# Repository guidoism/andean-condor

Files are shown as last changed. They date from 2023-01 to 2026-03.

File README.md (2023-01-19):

# Andean Condor

48 key monoblock split keyboard

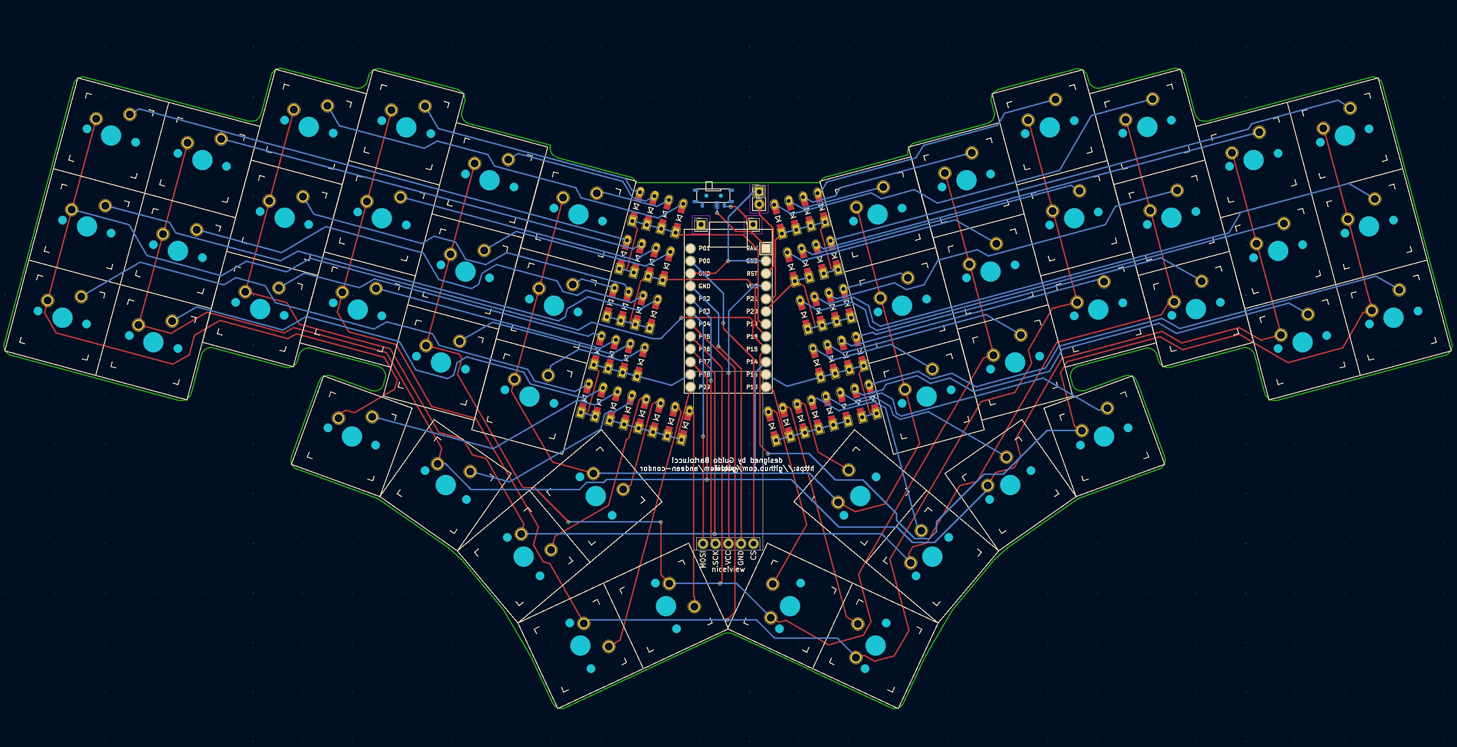
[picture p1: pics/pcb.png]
Picture of PCB


## Characteristics

- 3x6 core + 6 key thumb cluster per hand
- Pro-micro MCU footprint (note: it's right-side-up which apparently goes against the current trend)
- Nice!View headers (untested)

## Inspiration 

- Kyria -- A huge inpsiration, the thumb cluster in particular is taken directly from the Kyria
- Absolem -- Monoblock split and angles taken from Absolem

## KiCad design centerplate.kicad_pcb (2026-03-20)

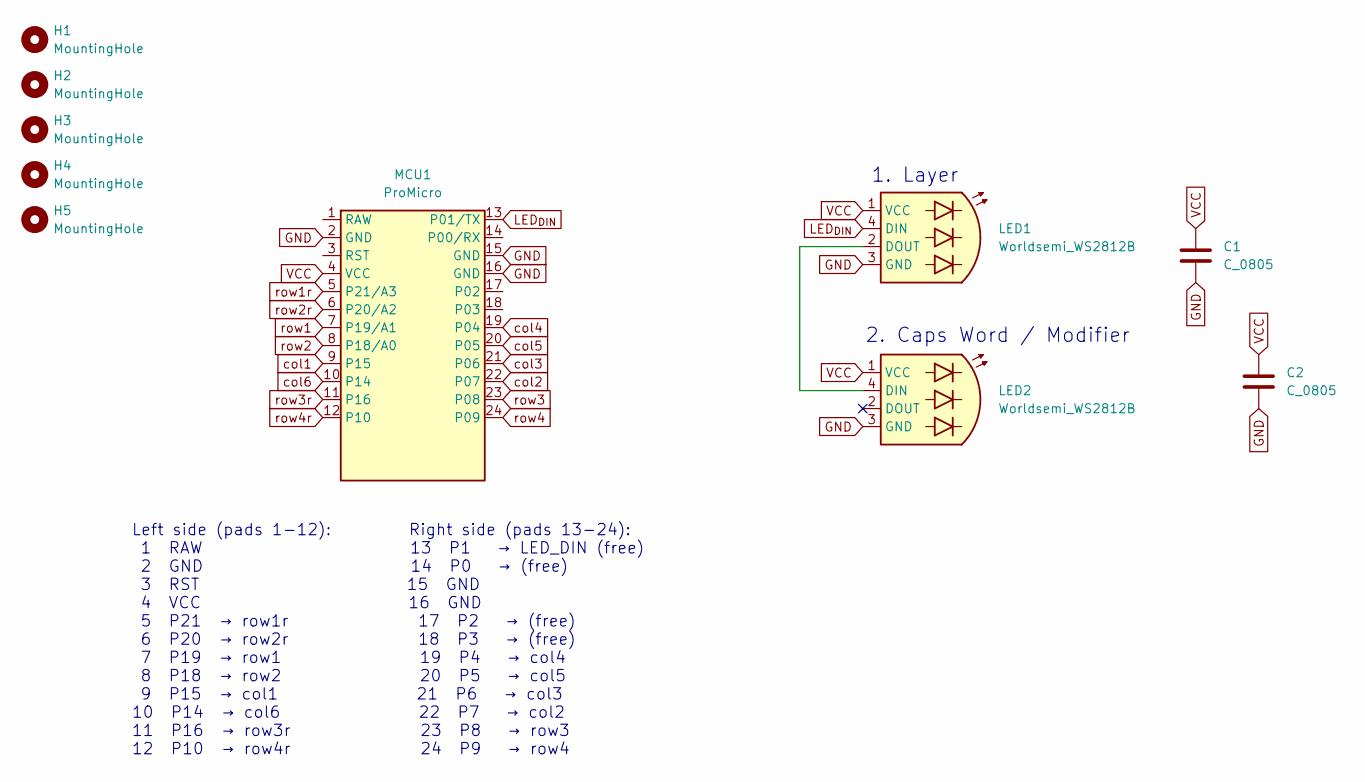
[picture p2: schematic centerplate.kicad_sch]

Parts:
C1, C2: C_0805; C_0805_2012Metric
H1, H2, H3, H4, H5: MountingHole; M2_HOLE_v3
LED1, LED2: Worldsemi_WS2812B; LED_WS2812B_PLCC4_5.0x5.0mm_P3.2mm
MCU1: ProMicro

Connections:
GND: C1.2, C2.2, LED1.3 (GND), LED2.3 (GND), MCU1.2 (GND), MCU1.15 (GND), MCU1.16 (GND)
LED_{DIN}: LED1.4 (DIN), MCU1.13 (P01/TX)
unnamed: LED1.2 (DOUT), LED2.4 (DIN)
VCC: C1.1, C2.1, LED1.1 (VCC), LED2.1 (VCC), MCU1.4 (VCC)
col1: MCU1.9 (P15)
col2: MCU1.22 (P07)
col3: MCU1.21 (P06)
col4: MCU1.19 (P04)
col5: MCU1.20 (P05)
col6: MCU1.10 (P14)
row1: MCU1.7 (P19/A1)
row1r: MCU1.5 (P21/A3)
row2: MCU1.8 (P18/A0)
row2r: MCU1.6 (P20/A2)
row3: MCU1.23 (P08)
row3r: MCU1.11 (P16)
row4: MCU1.24 (P09)
row4r: MCU1.12 (P10)

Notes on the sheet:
Left side (pads 1-12): Right side (pads 13-24): 1 RAW 13 P1 → LED_DIN (free) 2 GND 14 P0 → (free) 3 RST 15 GND 4 VCC 16 GND 5 P21 → row1r 17 P2 → (free) 6 P20 → row2r 18 P3 → (free) 7 P19 → row1 19 P4 → col4 8 P18 → row2 20 P5 → col5 9 P15 → col1 21 P6 → col3 10 P14 → col6 22 P7 → col2 11 P16 → row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
2. Caps Word / Modifier
1. Layer

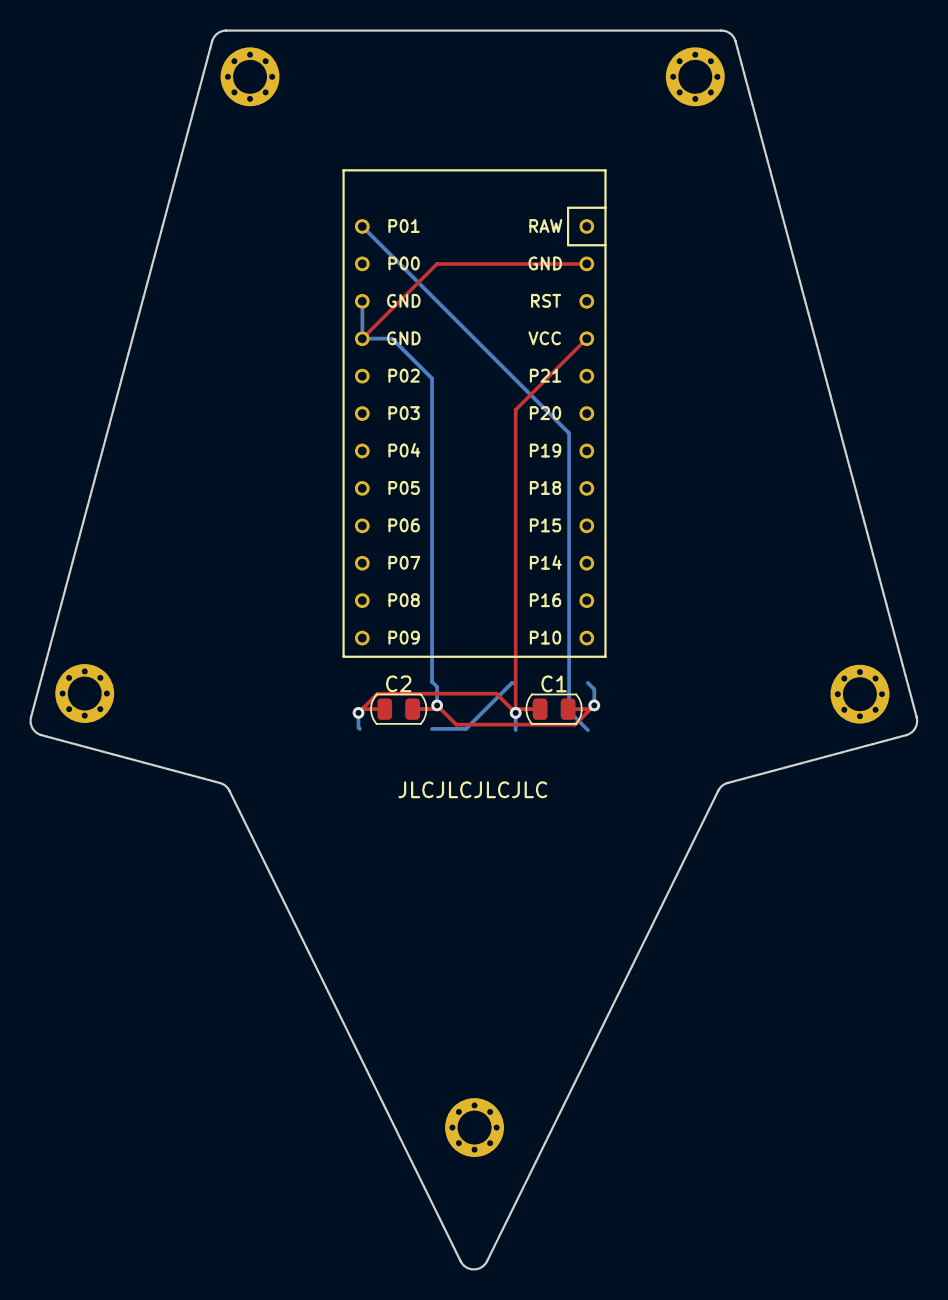
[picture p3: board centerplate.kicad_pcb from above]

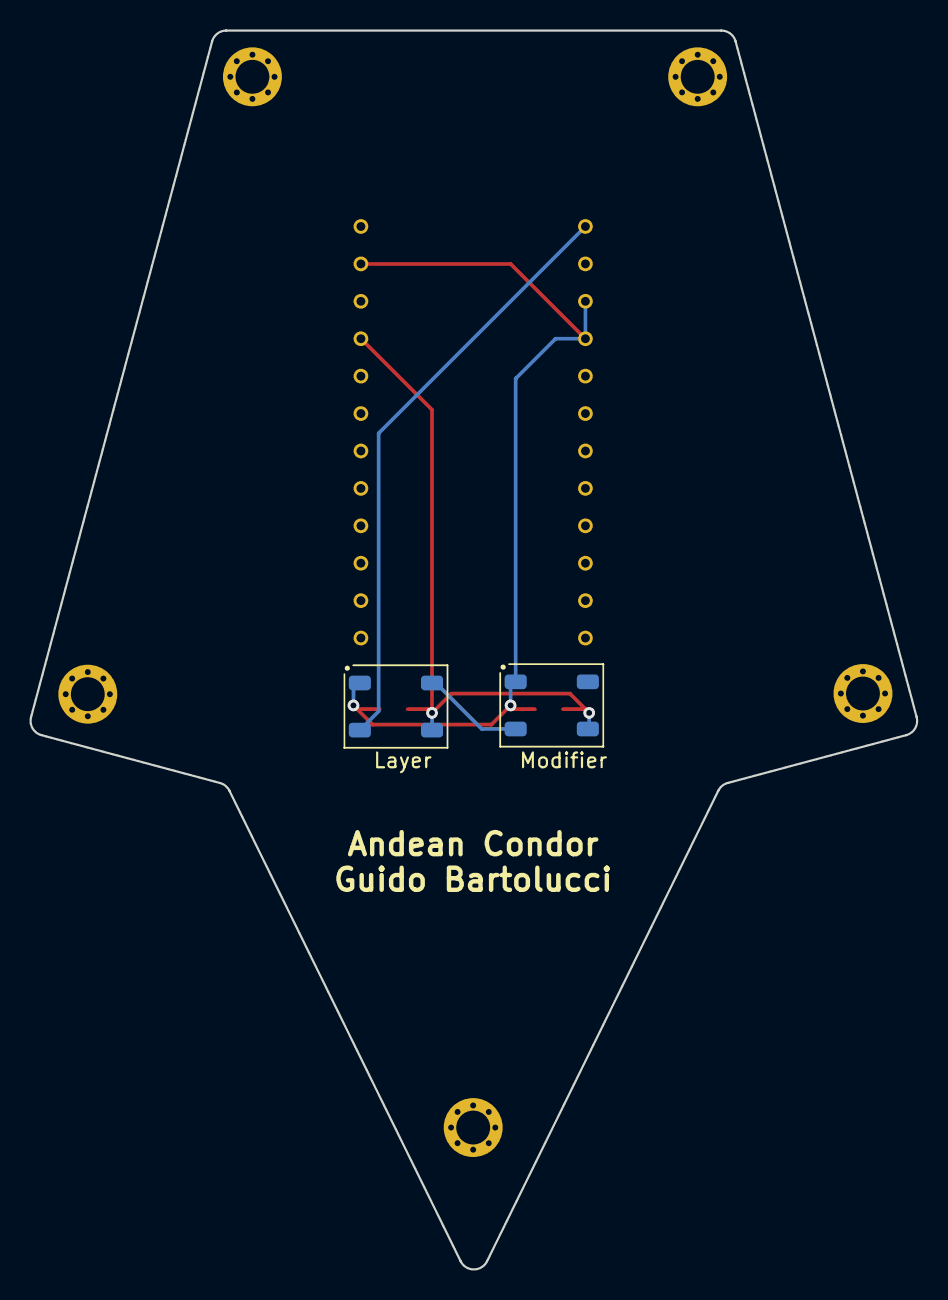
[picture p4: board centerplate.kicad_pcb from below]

Board: 2 copper layers, 60.2 x 84.1 mm, 10 parts (2 on the bottom side), 4 nets.

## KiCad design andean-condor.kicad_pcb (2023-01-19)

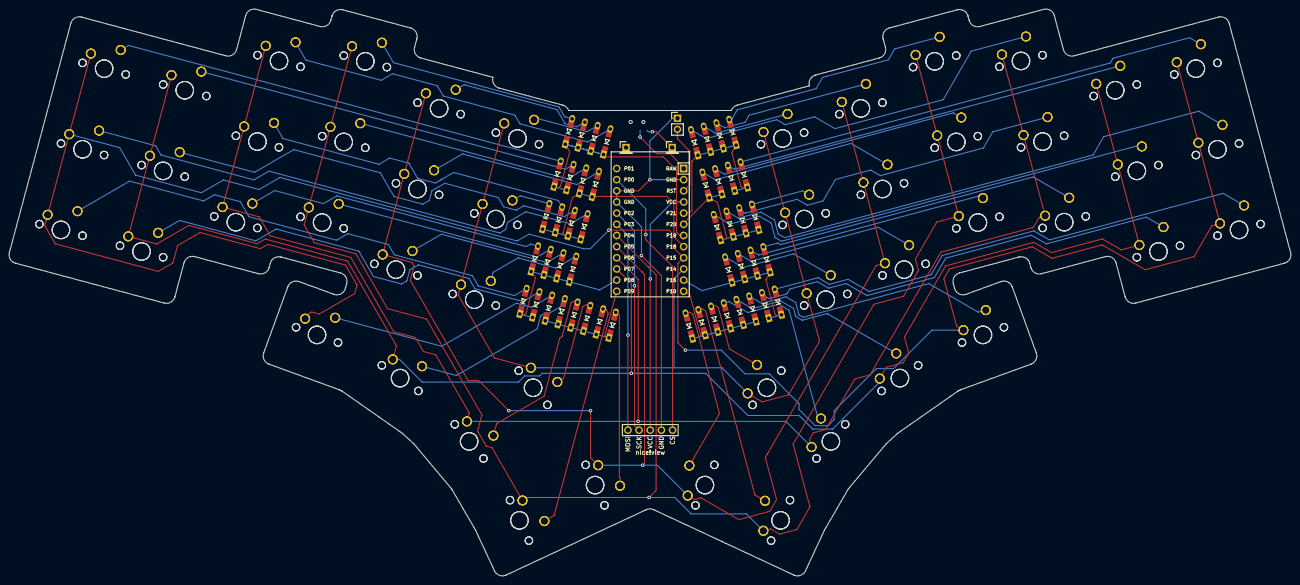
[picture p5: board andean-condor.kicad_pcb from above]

Board: 2 copper layers, 291.8 x 129.0 mm, 147 parts (1 on the bottom side), 68 nets.

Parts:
D33, D33#2, D34, D34#2, D35, D35#2, D36, D36#2, D37, D37#2, D38, D38#2, D39, D39#2, D40, D40#2, D41, D41#2, D42, D42#2, D43, D43#2, D44, D44#2, D45, D45#2, D46, D46#2, D47, D47#2, D48, D48#2, D49, D49#2, D50, D50#2, D51, D51#2, D52, D52#2, D53, D54, D55, D56, D57, D58, D59, D60: D; D3_TH_SMD_v2
MCU1: ProMicro
S1, S2, S3, S4, S5, S6, S7, S8, S9, S10, S11, S12, S13, S14, S15, S16, S17, S18, S19, S20, S21, S22, S23, S24, S25, S26, S27, S28, S29, S30, S31, S32, S33, S34, S35, S36, S37, S38, S39, S40, S41, S42, S43, S44, S45, S46, S47, S48, S49, S50, S51, S52, S53, S54, S55, S56, S57, S58, S59, S60, S61, S62, S63, S64, S65, S66, S67, S68, S69, S70, S71, S72, S73, S74, S75, S76, S77, S78, S79, S80, S81, S82, S83, S84, S85, S86, S87, S88, S89, S90, S91, S92, S93, S94, S95, S96: MX
SW1: SW_SPDT; switch-MSK-12C02-smd
display*: nice!view; nice_view

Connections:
GND: MCU1.2, MCU1.15, MCU1.16, display*.4
P0: MCU1.14, display*.5
P2: MCU1.17, display*.2
P3: MCU1.18, display*.1
RAW: MCU1.1, SW1.2
VCC: MCU1.4, display*.3
col1: MCU1.9, S1.2, S2.2, S3.2, S19.2, S25.2, S26.2, S27.2, S43.2, S49.2, S50.2, S51.2, S67.2, S73.2, S74.2, S75.2, S91.2
col2: MCU1.22, S4.2, S5.2, S6.2, S20.2, S28.2, S29.2, S30.2, S44.2, S52.2, S53.2, S54.2, S68.2, S76.2, S77.2, S78.2, S92.2
col3: MCU1.21, S7.2, S8.2, S9.2, S21.2, S31.2, S32.2, S33.2, S45.2, S55.2, S56.2, S57.2, S69.2, S79.2, S80.2, S81.2, S93.2
col4: MCU1.19, S10.2, S11.2, S12.2, S23.2, S34.2, S35.2, S36.2, S47.2, S58.2, S59.2, S60.2, S71.2, S82.2, S83.2, S84.2, S95.2
col5: MCU1.20, S13.2, S14.2, S15.2, S24.2, S37.2, S38.2, S39.2, S48.2, S61.2, S62.2, S63.2, S72.2, S85.2, S86.2, S87.2, S96.2
col6: MCU1.10, S16.2, S17.2, S18.2, S22.2, S40.2, S41.2, S42.2, S46.2, S64.2, S65.2, S66.2, S70.2, S88.2, S89.2, S90.2, S94.2
far_thumb: D55.2, S23.1, S95.1
far_top: D56.2, S24.1, S96.1
farpinky_bottom: D49.2, S1.1, S73.1
farpinky_home: D44#2.2, S2.1, S74.1
farpinky_top: D37#2.2, S3.1, S75.1
home_thumb: D53.2, S21.1, S93.1
home_top: D54.2, S22.1, S94.1
index_bottom: D47.2, S13.1, S85.1
index_home: D40#2.2, S14.1, S86.1
index_top: D34#2.2, S15.1, S87.1
inner_bottom: D48.2, S16.1, S88.1
inner_home: D41#2.2, S17.1, S89.1
inner_top: D35.2, S18.1, S90.1
middle_bottom: D46.2, S10.1, S82.1
middle_home: D39#2.2, S11.1, S83.1
middle_top: D33#2.2, S12.1, S84.1
mirror_far_thumb: D50.2, S47.1, S71.1
mirror_far_top: D49#2.2, S48.1, S72.1
mirror_farpinky_bottom: D60.2, S25.1, S49.1
mirror_farpinky_home: D42.2, S26.1, S50.1
mirror_farpinky_top: D40.2, S27.1, S51.1
mirror_home_thumb: D52#2.2, S45.1, S69.1
mirror_home_top: D51.2, S46.1, S70.1
mirror_index_bottom: D46#2.2, S37.1, S61.1
mirror_index_home: D37.2, S38.1, S62.1
mirror_index_top: D35#2.2, S39.1, S63.1
mirror_inner_bottom: D45#2.2, S40.1, S64.1
mirror_inner_home: D44.2, S41.1, S65.1
mirror_inner_top: D34.2, S42.1, S66.1
mirror_middle_bottom: D47#2.2, S34.1, S58.1
mirror_middle_home: D38.2, S35.1, S59.1
mirror_middle_top: D36.2, S36.1, S60.1
mirror_near_thumb: D57.2, S44.1, S68.1
mirror_pinky_bottom: D59.2, S28.1, S52.1
mirror_pinky_home: D41.2, S29.1, S53.1
mirror_pinky_top: D39.2, S30.1, S54.1
mirror_ring_bottom: D48#2.2, S31.1, S55.1
mirror_ring_home: D43#2.2, S32.1, S56.1
mirror_ring_top: D33.2, S33.1, S57.1
mirror_tucky_thumb: D58.2, S43.1, S67.1
near_thumb: D52.2, S20.1, S92.1
pinky_bottom: D50#2.2, S4.1, S76.1
pinky_home: D43.2, S5.1, S77.1
pinky_top: D38#2.2, S6.1, S78.1
ring_bottom: D45.2, S7.1, S79.1
ring_home: D42#2.2, S8.1, S80.1
ring_top: D36#2.2, S9.1, S81.1
row1: D33#2.1, D34#2.1, D35.1, D36#2.1, D37#2.1, D38#2.1, MCU1.7
row1r: D33.1, D34.1, D35#2.1, D36.1, D39.1, D40.1, MCU1.5
row2: D39#2.1, D40#2.1, D41#2.1, D42#2.1, D43.1, D44#2.1, MCU1.8
row2r: D37.1, D38.1, D41.1, D42.1, D43#2.1, D44.1, MCU1.6
row3: D45.1, D46.1, D47.1, D48.1, D49.1, D50#2.1, MCU1.23
row3r: D45#2.1, D46#2.1, D47#2.1, D48#2.1, D59.1, D60.1, MCU1.11
row4: D51#2.1, D52.1, D53.1, D54.1, D55.1, D56.1, MCU1.24
row4r: D49#2.1, D50.1, D51.1, D52#2.1, D57.1, D58.1, MCU1.12
tucky_thumb: D51#2.2, S19.1, S91.1

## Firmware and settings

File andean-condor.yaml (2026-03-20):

points:
  zones:
    matrix:
      anchor:
        rotate: 5
      columns:
        farpinky.key:
          column_net: col1
        pinky.key:
          column_net: col2
        ring.key:
          stagger: 12
          column_net: col3
        middle.key:
          stagger: 5
          column_net: col4
        index.key:
          stagger: -6
          column_net: col5
        inner.key:
          stagger: -2
          column_net: col6
      rows:
        bottom.row_net: row3
        home.row_net: row2
        top.row_net: row1
    thumbfan:
      anchor:
        ref: matrix_middle_bottom
        shift: [5.5, -25]
      columns:
        tucky.rows.top: $unset # EXAMPLE: <- Removing tucky top key
        near.rows.top: $unset
        tucky.key:
          splay: -5
          column_net: col1
        near.key:
          splay: -15
          origin: [-9.5, -9.5]
          column_net: col2
        home.key:
          splay: -15
          origin: [-9.5, -9.5]
          column_net: col3
        far.key:
          splay: -15
          origin: [-9.5, -9.5]
          column_net: col4
      rows:
        thumb.key.row_net: row4
        top.key.row_net: row4
        
  rotate: -20
  mirror:
    ref: thumbfan_far_top
    distance: 25
outlines:
  outline:
    main:
      what: rectangle
      where: /.*matrix.*|thumbfan|mirror_thumbfan.*/ # EXAMPLE: <- Using regex here
      size: 20
      fillet: 2
    middle:
      what: polygon
      points:
        - ref: matrix_inner_top
          shift: [$default_width/2,$default_height/2]
        - ref: thumbfan_tucky_thumb
          shift: [$default_width/2,$default_height/2]
        - ref: thumbfan_tucky_thumb
          shift: [$default_width/2,-$default_height/2]
        - ref: thumbfan_near_thumb
          shift: [0,-$default_height/2]
        - ref: thumbfan_home_thumb
          shift: [0,-$default_height/2]
        - ref: thumbfan_far_thumb
          shift: [$default_width/2,-$default_height/2]
        - ref: thumbfan_far_top
          shift: [$default_width/2,$default_height/2]
        - ref: mirror_thumbfan_far_thumb
          shift: [$default_width/2,-$default_height/2]
        - ref: mirror_thumbfan_home_thumb
          shift: [0,-$default_height/2]
        - ref: mirror_thumbfan_near_thumb
          shift: [0,-$default_height/2]
        - ref: mirror_thumbfan_tucky_thumb
          shift: [$default_width/2,-$default_height/2]
        - ref: mirror_thumbfan_tucky_thumb
          shift: [$default_width/2,$default_height/2]
        - ref: mirror_matrix_inner_top
          shift: [$default_width/2,$default_height/2]
  plate:
    - what: outline
      name: outline

  mxkeyoutlines:
    - what: rectangle
      where: true
      bound: false
      size: [19, 19]

  keyholes:
    - what: rectangle
      where: true
      bound: false
      size: [14, 14]

  top_thumb_keys:
    - what: rectangle
      where: [thumbfan_far_top, mirror_thumbfan_far_top, thumbfan_home_top, mirror_thumbfan_home_top]
      bound: false
      size: [15, 15]

  center_top_plate:
    - what: polygon
      fillet: 1
      points: 
        - ref: matrix_inner_top
          shift: [9.5+1, 9.5]
        - ref: matrix_inner_bottom
          shift: [9.5+1, -9.5/2+3]
        - ref: matrix_inner_bottom
          shift: [9.5+15, -9.5/2+3]
        #- ref: thumbfan_far_top
        #  shift: [9.5, 9.5]
        - ref:
            aggregate:
              method: average
              parts:
                - ref: thumbfan_far_top
                - ref: mirror_thumbfan_far_top
            rotate: 0
        - ref: mirror_matrix_inner_bottom
          shift: [9.5+15, -9.5/2+3]
        - ref: mirror_matrix_inner_bottom
          shift: [9.5+1, -9.5/2+3]
        - ref: mirror_matrix_inner_top
          shift: [9.5+1, 9.5]

  keeb_with_centerplate:
    - name: outline
    - operation: subtract
      name: center_top_plate
    - operation: subtract
      name: mxkeyoutlines      

  mounting_top_flange:
    - what: polygon
      fillet: 2
      points:
        - ref: matrix_farpinky_top
          shift: [-9.5-2, 9.5+2]
        - ref: mirror_matrix_farpinky_top
          shift: [-9.5-2, 9.5+2]
        - ref: mirror_matrix_farpinky_bottom
          shift: [-9.5-2, -9.5]
        - ref: mirror_thumbfan_tucky_thumb
          shift: [9.5, -9.5-1]
        - ref: thumbfan_far_top
        - ref: thumbfan_tucky_thumb
          shift: [9.5, -9.5-1]        
        - ref: matrix_farpinky_bottom
          shift: [-9.5-2, -9.5]
  
  mcu_cutout:
    - what: rectangle
      size: [24, 50]
      where.aggregate.parts: [matrix_inner_top, mirror_matrix_inner_top]
      adjust.shift: [0, -20]
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

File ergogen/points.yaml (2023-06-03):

matrix_farpinky_bottom:
  x: 0
  'y': 0
  r: -15
  meta:
    stagger: 0
    spread: 19
    splay: 0
    origin:
      - 0
      - 0
    orient: 0
    shift:
      - 0
      - 0
    rotate: 0
    width: 18
    height: 18
    padding: 19
    autobind: 10
    skip: false
    asym: both
    colrow: farpinky_bottom
    name: matrix_farpinky_bottom
    column_net: col1
    row_net: row3
    zone: &ref_1
      columns:
        farpinky: &ref_0
          key:
            column_net: col1
          rows: {}
          name: farpinky
        pinky: &ref_2
          key:
            column_net: col2
          rows: {}
          name: pinky
        ring: &ref_3
          key:
            stagger: 12
            column_net: col3
          rows: {}
          name: ring
        middle: &ref_4
          key:
            stagger: 5
            column_net: col4
          rows: {}
          name: middle
        index: &ref_5
          key:
            stagger: -6
            column_net: col5
          rows: {}
          name: index
        inner: &ref_6
          key:
            stagger: -2
            column_net: col6
          rows: {}
          name: inner
      rows:
        bottom:
          row_net: row3
        home:
          row_net: row2
        top:
          row_net: row1
      name: matrix
    col: *ref_0
    row: bottom
    bind:
      - 10
      - 0
      - 0
      - 0
    mirrored: false
matrix_farpinky_home:
  x: 4.9175619
  'y': 18.3525907
  r: -15
  meta:
    stagger: 0
    spread: 19
    splay: 0
    origin:
      - 0
      - 0
    orient: 0
    shift:
      - 0
      - 0
    rotate: 0
    width: 18
    height: 18
    padding: 19
    autobind: 10
    skip: false
    asym: both
    colrow: farpinky_home
    name: matrix_farpinky_home
    column_net: col1
    row_net: row2
    zone: *ref_1
    col: *ref_0
    row: home
    bind:
      - 10
      - 10
      - 10
      - 0
    mirrored: false
matrix_farpinky_top:
  x: 9.8351238
  'y': 36.7051815
  r: -15
  meta:
    stagger: 0
    spread: 19
    splay: 0
    origin:
      - 0
      - 0
    orient: 0
    shift:
      - 0
      - 0
    rotate: 0
    width: 18
    height: 18
    padding: 19
    autobind: 10
    skip: false
    asym: both
    colrow: farpinky_top
    name: matrix_farpinky_top
    column_net: col1
    row_net: row1
    zone: *ref_1
    col: *ref_0
    row: top
    bind:
      - 0
      - 10
      - 10
      - 0
    mirrored: false
matrix_pinky_bottom:
  x: 18.3525907
  'y': -4.9175619
  r: -15
  meta:
    stagger: 0
    spread: 19
    splay: 0
    origin:
      - 0
      - 0
    orient: 0
    shift:
      - 0
      - 0
    rotate: 0
    width: 18
    height: 18
    padding: 19
    autobind: 10
    skip: false
    asym: both
    colrow: pinky_bottom
    name: matrix_pinky_bottom
    column_net: col2
    row_net: row3
    zone: *ref_1
    col: *ref_2
    row: bottom
    bind:
      - 10
      - 0
      - 0
      - 10
    mirrored: false
matrix_pinky_home:
  x: 23.2701526
  'y': 13.4350288
  r: -15
  meta:
    stagger: 0
    spread: 19
    splay: 0
    origin:
      - 0
      - 0
    orient: 0
    shift:
      - 0
      - 0
    rotate: 0
    width: 18
    height: 18
    padding: 19
    autobind: 10
    skip: false
    asym: both
    colrow: pinky_home
    name: matrix_pinky_home
    column_net: col2
    row_net: row2
    zone: *ref_1
    col: *ref_2
    row: home
    bind:
      - 10
      - 10
      - 10
      - 10
    mirrored: false
matrix_pinky_top:
  x: 28.1877145
  'y': 31.7876196
  r: -15
  meta:
    stagger: 0
    spread: 19
    splay: 0
    origin:
      - 0
      - 0
    orient: 0
    shift:
      - 0
      - 0
    rotate: 0
    width: 18
    height: 18
    padding: 19
    autobind: 10
    skip: false
    asym: both
    colrow: pinky_top
    name: matrix_pinky_top
    column_net: col2
    row_net: row1
    zone: *ref_1
    col: *ref_2
    row: top
    bind:
      - 0
      - 10
      - 10
      - 0
    mirrored: false
matrix_ring_bottom:
  x: 39.8110099
  'y': 1.7559862
  r: -15
  meta:
    stagger: 12
    spread: 19
    splay: 0
    origin:
      - 0
      - 0
    orient: 0
    shift:
      - 0
      - 0
    rotate: 0
    width: 18
    height: 18
    padding: 19
    autobind: 10
    skip: false
    asym: both
    colrow: ring_bottom
    name: matrix_ring_bottom
    column_net: col3
    row_net: row3
    zone: *ref_1
    col: *ref_3
    row: bottom
    bind:
      - 10
      - 0
      - 0
      - 10
    mirrored: false
matrix_ring_home:
  x: 44.7285718
  'y': 20.1085769
  r: -15
  meta:
    stagger: 12
    spread: 19
    splay: 0
    origin:
      - 0
      - 0
    orient: 0
    shift:
      - 0
      - 0
    rotate: 0
    width: 18
    height: 18
    padding: 19
    autobind: 10
    skip: false
    asym: both
    colrow: ring_home
    name: matrix_ring_home
    column_net: col3
    row_net: row2
    zone: *ref_1
    col: *ref_3
    row: home
    bind:
      - 10
      - 10
      - 10
      - 10
    mirrored: false
matrix_ring_top:
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

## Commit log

2023-01-19 Inital commit of the files
    [andean-condor.kicad_pcb]
2023-01-19 Added some text to the pcb
    [andean-condor.kicad_pcb]
2023-01-19 Add pic of pcb
2024-12-10 Created outline for switchplate
2024-12-10 Fix update to thumbfan outline
    [andean-condor.yaml]
2024-12-10 Added place to put mounting holes on the top sides
2024-12-10 Added the second set of mounting additions to the top
2024-12-10 Added mounting holes to the top
2024-12-10 Changed switch plate to be more regular shaped
2024-12-10 Added screw holes
2024-12-10 Added bottom plate
2024-12-11 Added cutout for mcu to be accessed
    This is in order to reboot it or remove it... hopefully
    [andean-condor.yaml]
2024-12-11 Added switch plate to pcbs
2024-12-13 Added pcb demo
2026-03-20 Added centerpiece pcb
    [centerplate.kicad_pcb, centerplate.kicad_sch]
